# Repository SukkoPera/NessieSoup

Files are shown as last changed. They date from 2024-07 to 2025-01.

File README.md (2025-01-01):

# NessieSoup
NessieSoup is a simple adapter that allows connecting Super Nintendo controllers to a Commodore 64, 128 or Plus/4.

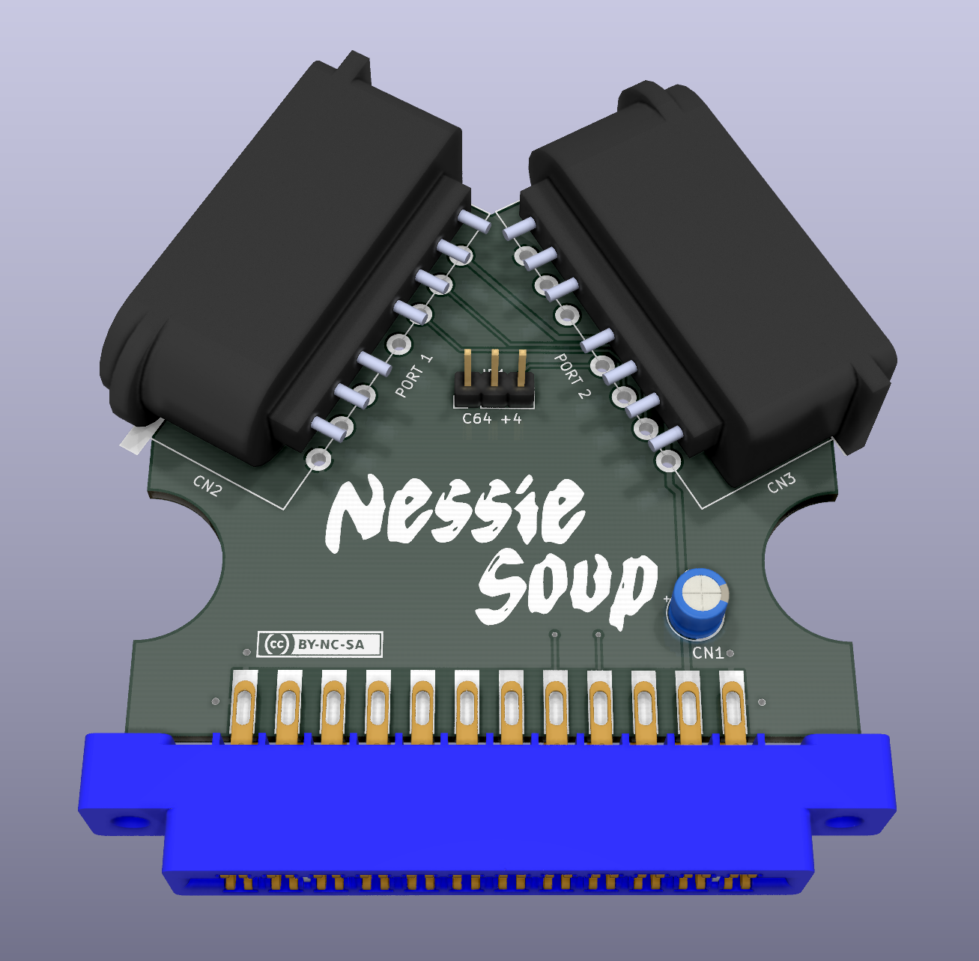
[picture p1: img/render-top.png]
Board


## Summary
The game [Attack of the PETSCII Robots](https://www.the8bitguy.com/product/petscii-robots/) by The 8-Bit Guy supports SNES controllers when running on the C64, VIC-20, Plus/4, and PET with a custom adapter. While I didn't have the game (nor the adapter), I was able to figure out how it works and I noticed that it could easily be expanded to support more than one controller and advanced peripherals, such as the *SNES MultiTap* and (possibly) the [Super Scope](https://en.wikipedia.org/wiki/Super_Scope).

So I designed a new PCB with 2 controllers ports: the first port is designed to be fully compatible with the original adapter (which means it should work with PETSCII Robots, but I was unable to test it), while the second one supports either a second controller or the more advanced peripherals.

The project also has the purpose of openly documenting this adapter, so that more games can be developed with support for SNES controllers (and all their buttons!).

The board plugs in the User Port, which means that it can also be used on a C16 or C116 through [a User Port card](https://github.com/SukkoPera/16up).

## Assembly
Get the SNES and userport connectors on AliExpress & similar sites.

The capacitor is optional.

## Programming
The board is completely passive, so it's all down to the software. This means you should first of all get familiar with the [SNES controller protocol](https://github.com/SukkoPera/NessieSoup/wiki/Super-Nintendo-Entertainment-System:-Pinouts-&-Protocol), then the following will start to make sense:

|Signal |Userport Pin +4|Userport Pin C64/128|Userport Pin VIC-20|Userport Pin PET|
|---|---|---|---|---|
|Latch |J/D6 |J/PB5 |J/PB5 |J/PA5 |
|Clock |F/D7 |F/PB3 |F/PB3 |F/PA3 |
|D0 (Port 1)|K/D1 |K/PB6 |K/PB6 |K/PA6 |
|D0 (Port 2)|B/D0 |C/PB0 |C/PB0 |C/PB0 |
|D1 (Port 2)|4/D2 | | | |
|PP (Port 2)|5/D3 | | | |

*NOTE: The adapter has only been tested on the +4 and C64, pinouts for other computers is only provided as a reference, use at your own risk.*

Note that JP1 must be set to **+4** only when the board is connected to a +4, C16 or C116 computer, use the **C64** position in all other cases.

Some example code for controller detection and polling is provided on the [Wiki](https://github.com/SukkoPera/NessieSoup/wiki).

Code for reading the SNES MultiTap and the Super Scope has not been developed yet. The *D1* and *PP* signals are only needed for these purposes and the way they are connected might only work on the +4. More work is needed in this regard, feel free to contribute ;).

## Releases
If you want to get this board produced, you are recommended to get [the latest release](https://github.com/SukkoPera/NessieSoup/releases) rather than the current git version, as the latter might be under development and is not guaranteed to be working.

Every release is accompanied by its Bill Of Materials (BOM) file and any relevant notes about it, which you are recommended to read carefully.

## License
The NessieSoup documentation, including the design itself, is copyright &copy; SukkoPera 2024 and is licensed under the [Creative Commons Attribution-NonCommercial-ShareAlike 4.0 International License](https://creativecommons.org/licenses/by-nc-sa/4.0/).

This documentation is distributed *as is* and WITHOUT ANY EXPRESS OR IMPLIED WARRANTIES whatsoever with respect to its functionality, operability or use, including, without limitation, any implied warranties OF MERCHANTABILITY, SATISFACTORY QUALITY, FITNESS FOR A PARTICULAR PURPOSE or infringement. We expressly disclaim any liability whatsoever for any direct, indirect, consequential, incidental or special damages, including, without limitation, lost revenues, lost profits, losses resulting from business interruption or loss of data, regardless of the form of action or legal theory under which the liability may be asserted, even if advised of the possibility or likelihood of such damages.

## Support the Project
If you want to get some boards manufactured, you can get them from PCBWay through this link:

PCB from PCBWay (https://www.pcbway.com/project/shareproject/NessieSoup_Super_Nintendo_Controller_Adapter_for_the_Commodore_64_VIC_20_and_8b1f1d4c.html)

You get my gratitude and cheap, professionally-made and good quality PCBs, I get some credit that will help with this and [other projects](https://www.pcbway.com/project/member/shareproject/?bmbid=41100). You won't even have to worry about the various PCB options, it's all pre-configured for you!

Also, if you still have to register, [you can use this link](https://www.pcbway.com/setinvite.aspx?inviteid=41100) to get some bonus initial credit (and yield me some more).

You can also buy me a coffee if you want:

<a href='https://ko-fi.com/L3L0U18L' target='_blank'>Buy Me a Coffee at ko-fi.com</a>

## Thanks
* The 8-Bit Guy for designing the original adapter.
* wepfont for the [M Malaming](https://www.fontspace.com/m-malaming-font-f118544) font used in the logo.

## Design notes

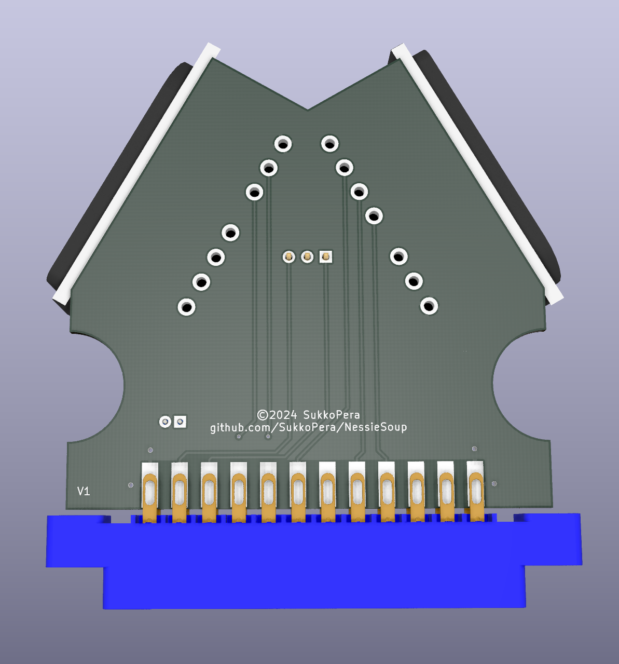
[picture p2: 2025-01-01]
img/render-bottom.png

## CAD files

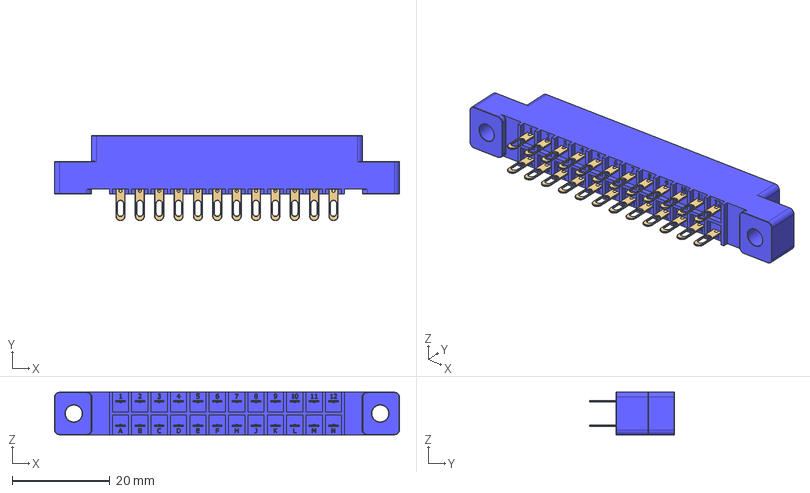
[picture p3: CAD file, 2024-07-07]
3dModels/C64 Userport Connector.STEP
70.6 x 17.5 x 8.71 mm
Card Edge Connector 2x12 (Userport)
Metallzunge x 24
Trenner Edge Conn x 2

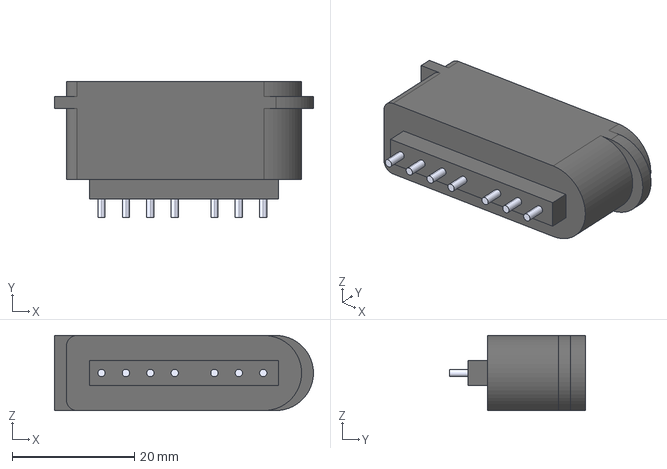
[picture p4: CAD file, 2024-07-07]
3dModels/snes_connector_v1.STEP
42.4 x 22.4 x 12.3 mm
body_v1
pin18mm x 7

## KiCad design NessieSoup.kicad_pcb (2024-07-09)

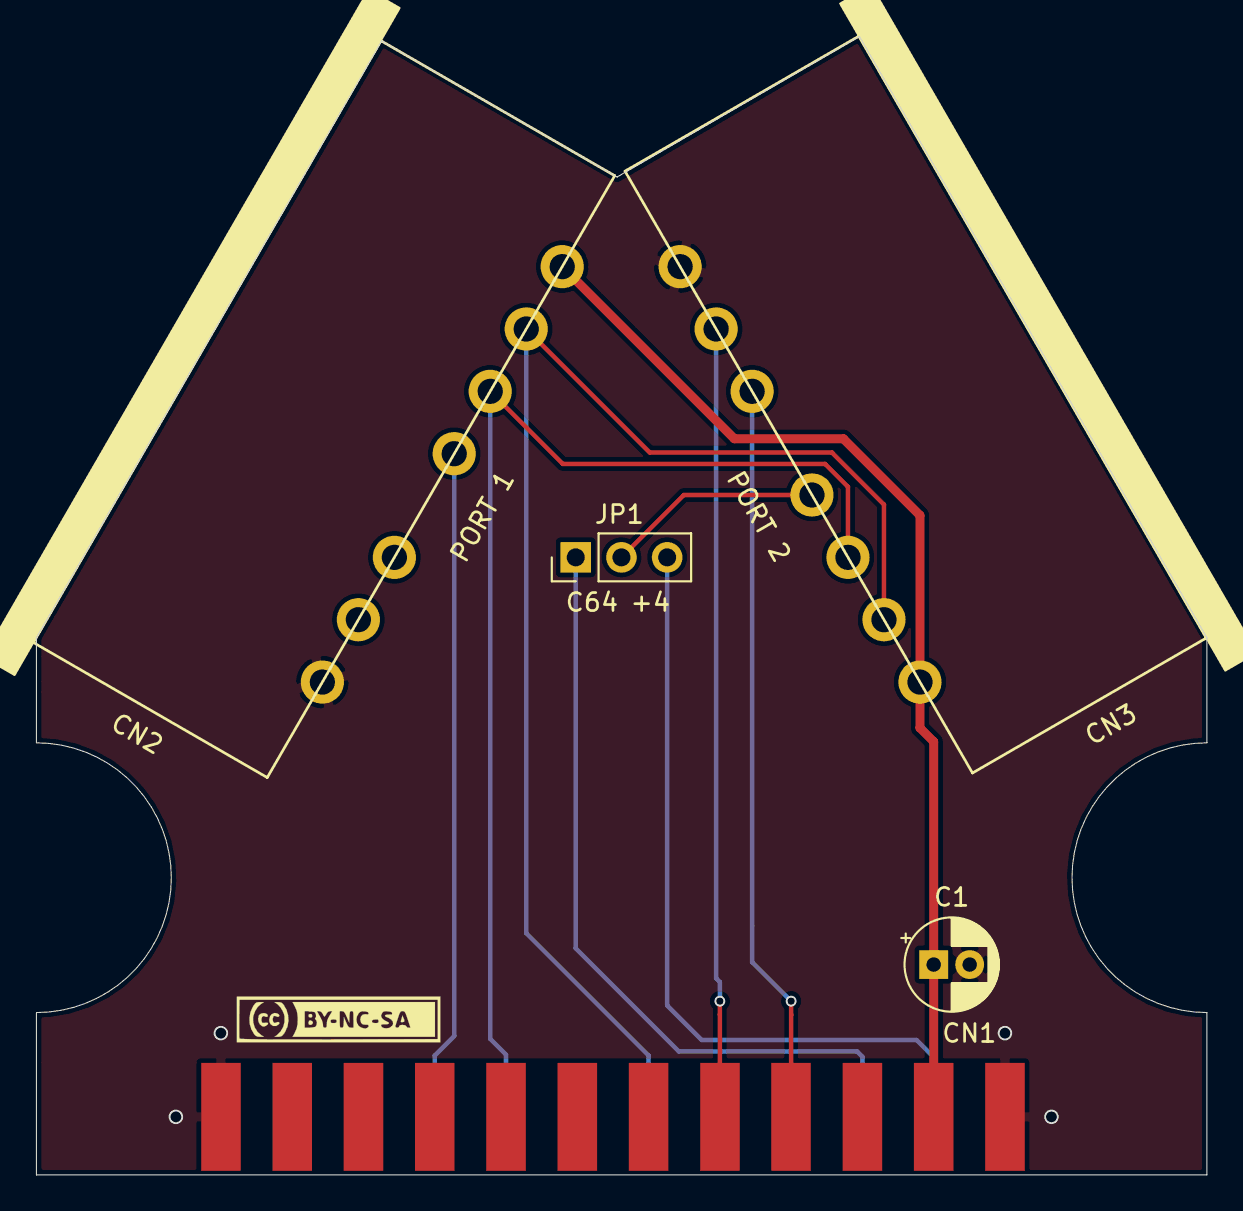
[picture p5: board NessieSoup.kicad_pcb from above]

Board: 2 copper layers, 65.0 x 63.2 mm, 8 parts (0 on the bottom side), 10 nets.

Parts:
C1: 47u; CP_Radial_D5.0mm_P2.00mm
CN1: PLUS4_USERPORT; UserPortFemale
CN2: CONN_SNES_1; CONN_SNES
CN3: CONN_SNES_2; CONN_SNES
JP1: JMP_16_64; PinHeader_1x03_P2.54mm_Vertical
V0: LICENSE; cc_by_nc_sa_small
V1: LOGO1; Logo1
V2: LOGO2; Logo2

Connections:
+5V: C1.1, CN1.2, CN2.7, CN3.7
/clock: CN1.F, CN2.6, CN3.6
/latch: CN1.J, CN2.5, CN3.5
/port1_d0: CN1.K, CN2.4
/port2_d0: CN3.4, JP1.2
/port2_d1: CN1.4, CN3.3
/port2_pp: CN1.5, CN3.2
GND: C1.2, CN1.1, CN1.12, CN1.A, CN1.N, CN2.1, CN3.1
unnamed: CN1.B, JP1.3
unnamed: CN1.C, JP1.1

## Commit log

2024-07-08 Almost there
    [NessieSoup.kicad_pcb, NessieSoup.sch]
2024-07-08 Add capacitor Yeah, we must have at least one component...
    [NessieSoup.kicad_pcb, NessieSoup.sch]
2024-07-09 Refine shape
    [NessieSoup.kicad_pcb, NessieSoup.sch]
2024-07-09 Add +4/C64 switch
    [NessieSoup.kicad_pcb]

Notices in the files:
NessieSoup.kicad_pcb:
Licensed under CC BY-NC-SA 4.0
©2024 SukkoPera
